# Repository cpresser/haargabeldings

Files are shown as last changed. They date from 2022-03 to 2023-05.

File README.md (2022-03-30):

# HaarGabelDings

action shot
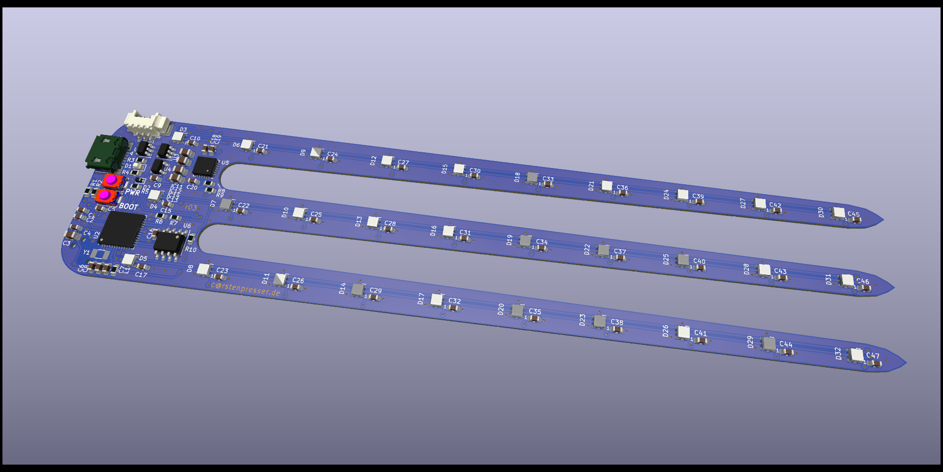
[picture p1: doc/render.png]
render


# Hardware
The current revision uses a SAMD21 MCU, making it compatible with the `Arduino Zero` and the `Adafruit Feather M0 Express`.

Since there was no space left to route tracks or put parts, no other Pins are broken out. Also there is no USB ESD Protection.

## PCB
Export gerbers and order it at you favorite fab.
The first proto used 2mm FR4 instead of the default 1.5mm and is quite usable. Perhaps 3mm is even better.. who knows? One might even try to glue two PCBs together somehow to make the whole thing stiffer.

## Coating?
Some coating is required, otherwise the assembled PCB has to many sharp edges which makes it unusable as a hairpiece. I used epoxy for the prototype. Make sure to mask the switch, debugger-port and USB-connector. You don't want them covered in epoxy (I have been there, don't repeat my mistakes).

## BOM
Nope. I might add one later.

All parts are available at digikey though - assuming there is no global semiconductor supplychain crisis.

## Battery
Connect any single cell lipo battery. I recommend to get one with a build in battery management system.

# Software
The v3 version is supposed to be compatible with the "Adafruit Feather M0 Express", which means one can use micropython.

## USB Bootloader
The Adafruit or Arduino Bootloader should work.

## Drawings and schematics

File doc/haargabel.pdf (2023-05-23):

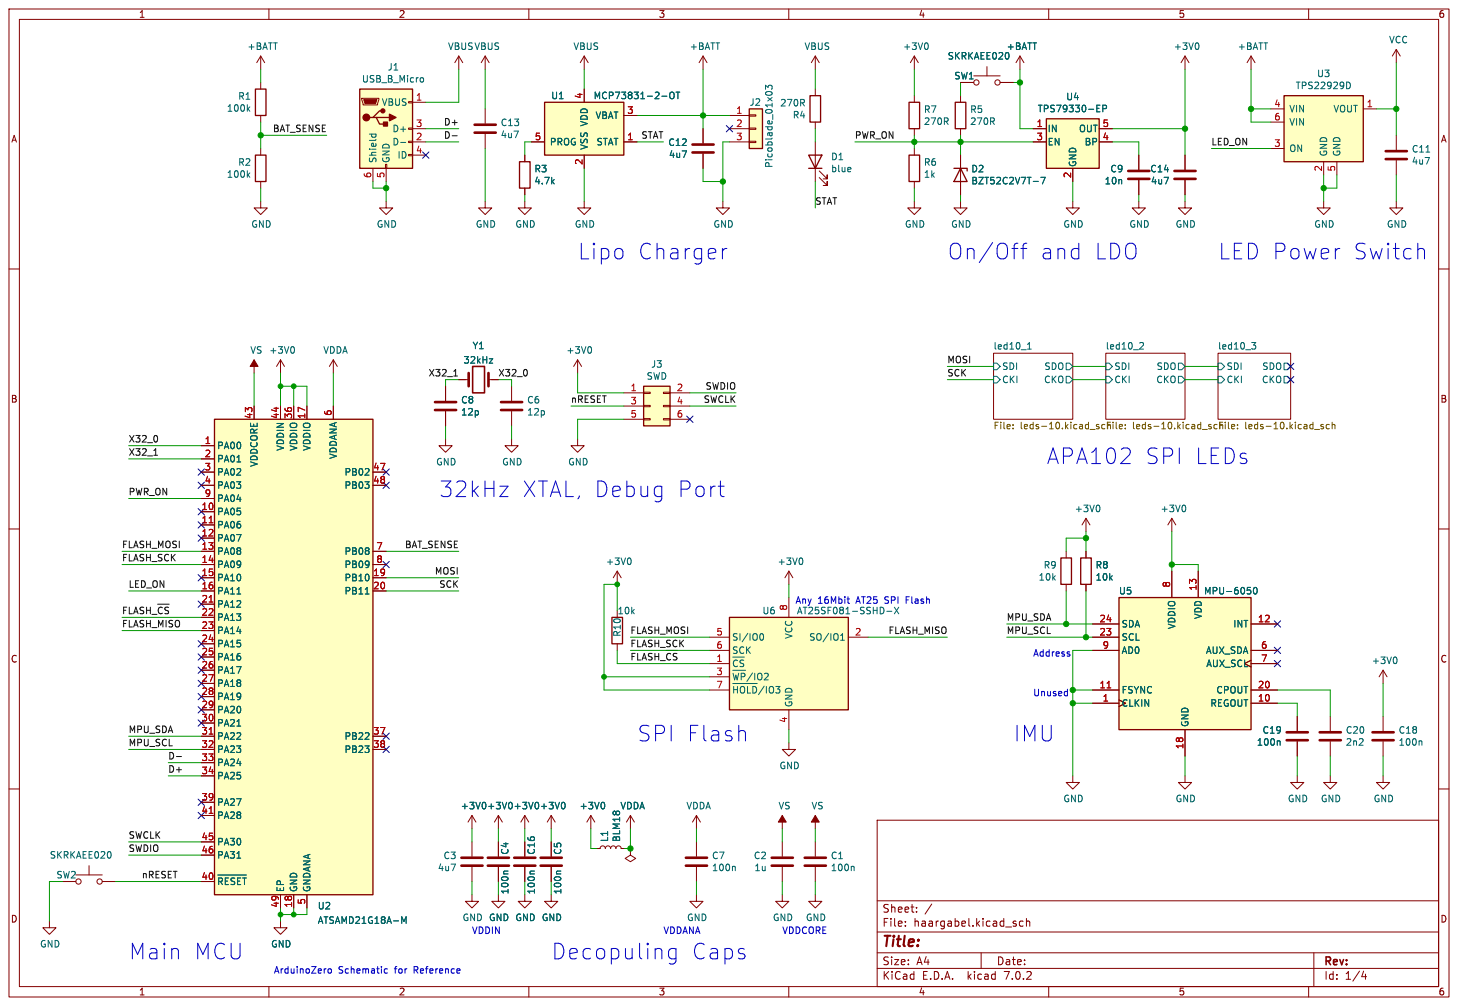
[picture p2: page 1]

2 EN 3 BP 4 OUT 5 SW1 SKRKAEE020+BATT D2BZT52C2V7T-7 C12

2 EN 3 BP 4 OUT 5 U4 TPS79330-EP GND

4u7 GND GND GND GND

Unused Address Lipo Charger

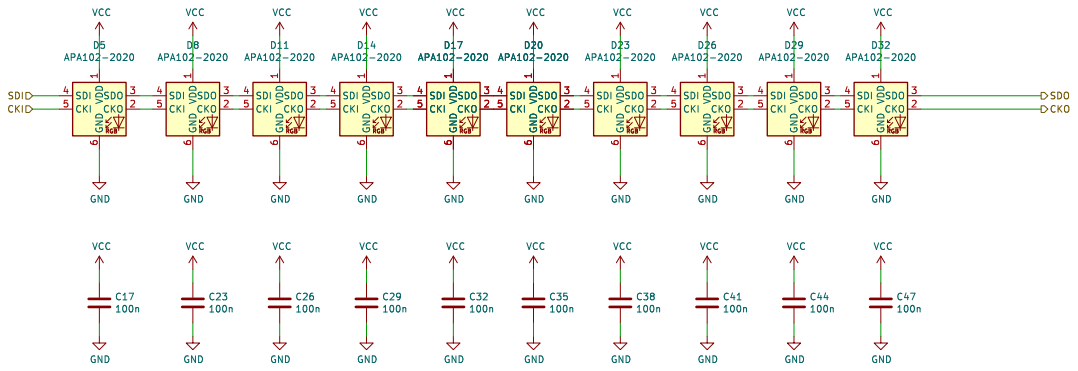
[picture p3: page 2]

6 D32 APA102-2020 GND GND GND GND GND

1 CKO 2 SDO 3 SDI 4 CKI 5 GND
RGB VDD

Id: 2/4 Title: File: leds-10.kicad_sch Sheet: /led10_1/ GND

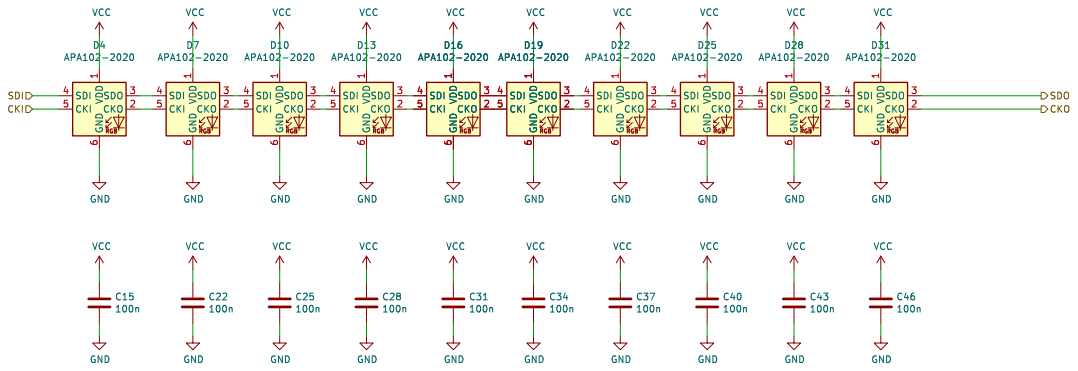
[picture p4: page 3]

6 D28 APA102-2020 GND GND GND GND GND

1 CKO 2 SDO 3 SDI 4 CKI 5 GND
RGB VDD

Id: 3/4 Title: File: leds-10.kicad_sch Sheet: /led10_2/

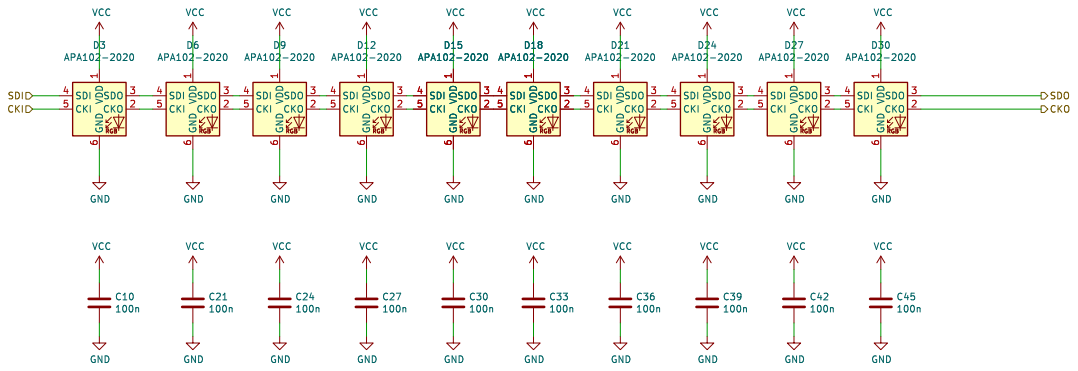
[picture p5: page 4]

6 D27 APA102-2020 VCC GND GND GND GND GND

1 CKO 2 SDO 3 SDI 4 CKI 5 GND
RGB VDD

Id: 4/4 Title: File: leds-10.kicad_sch Sheet: /led10_3/ GND

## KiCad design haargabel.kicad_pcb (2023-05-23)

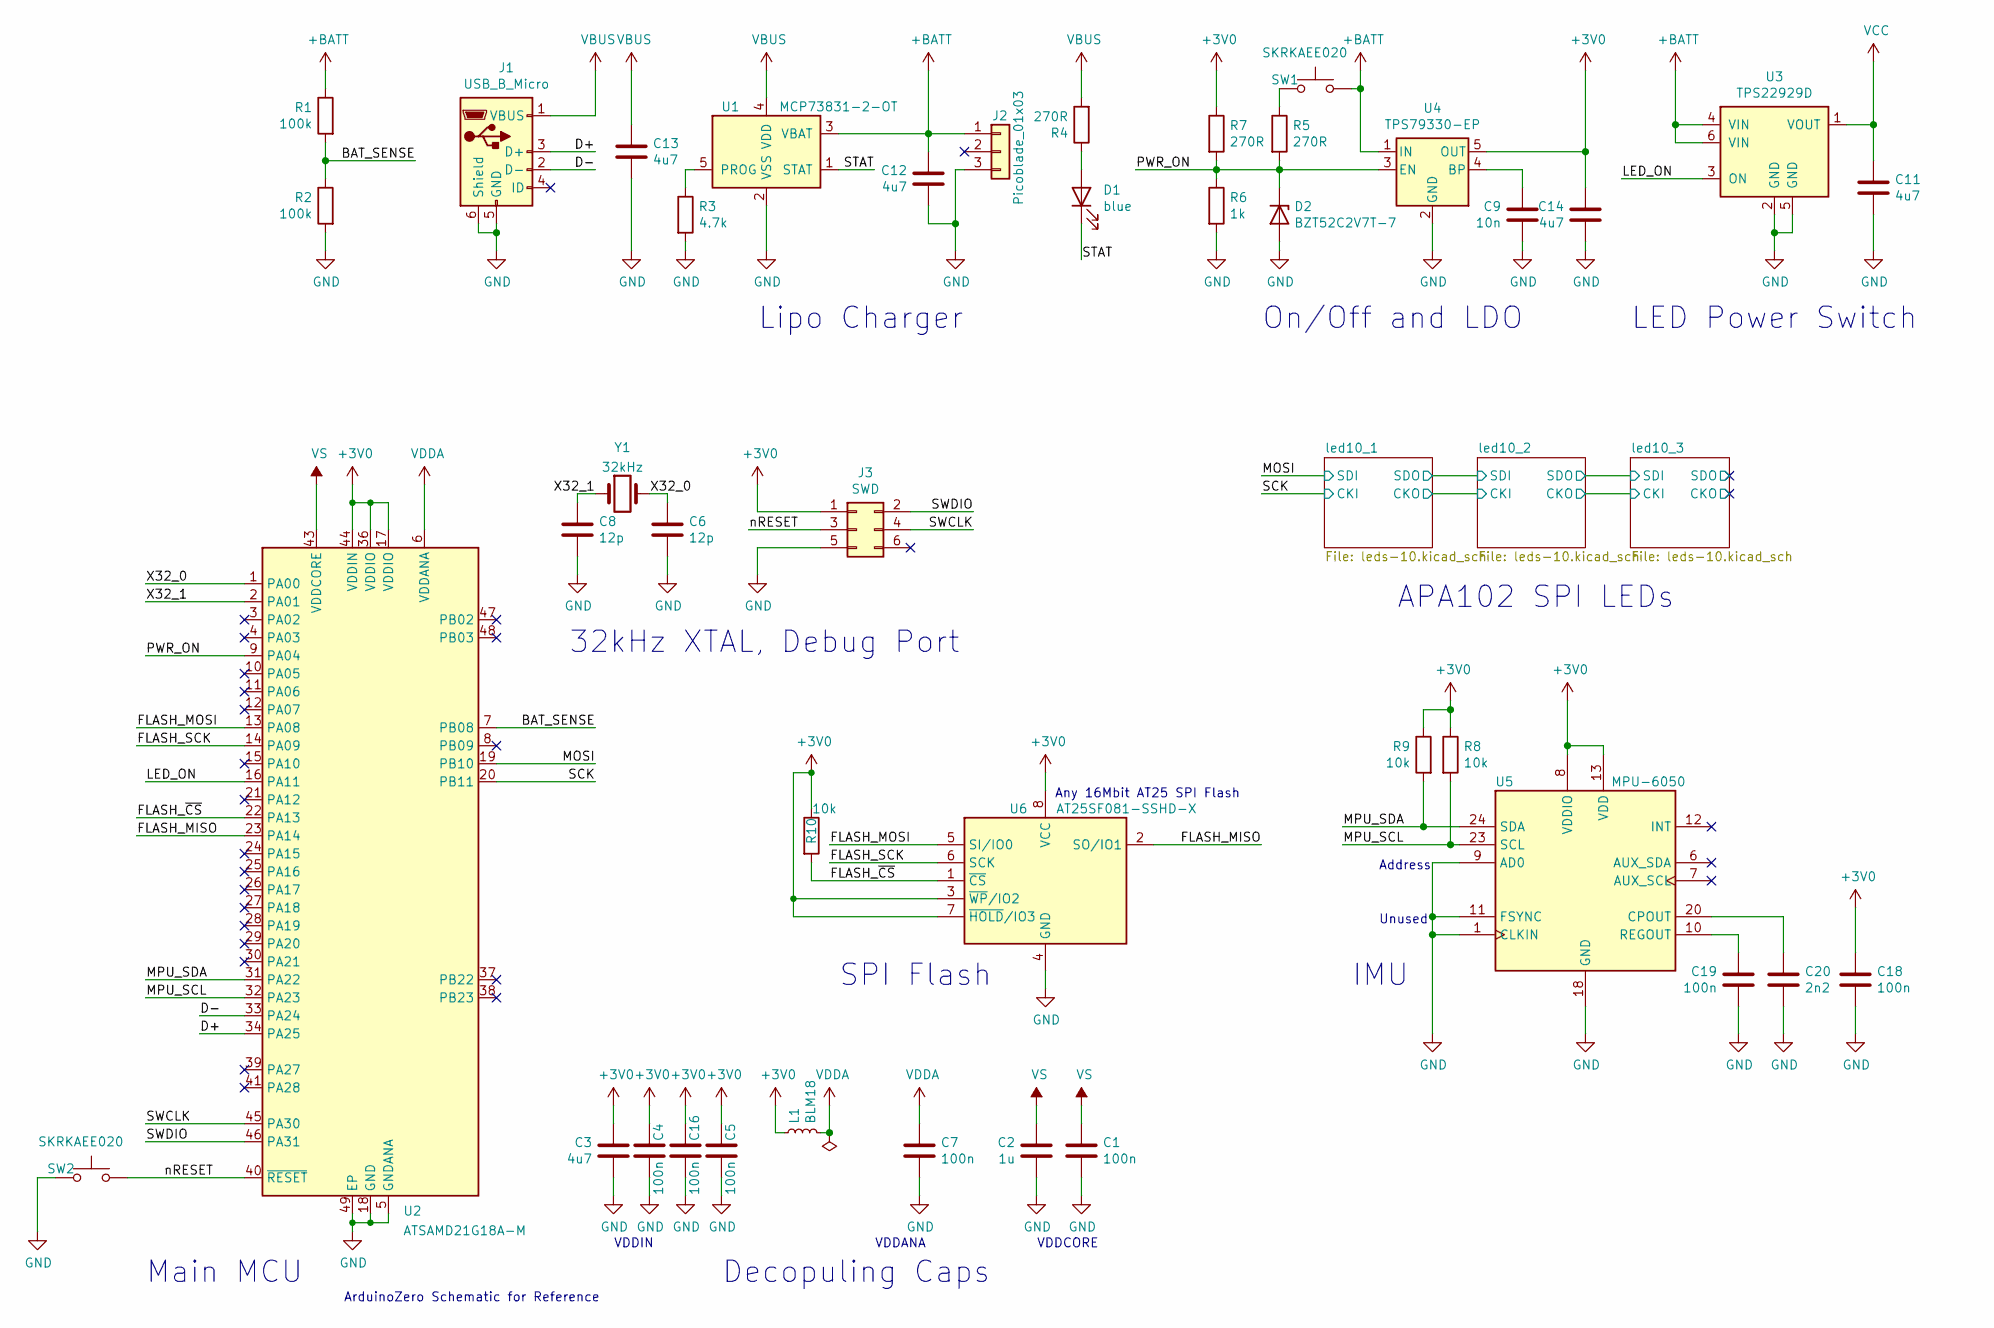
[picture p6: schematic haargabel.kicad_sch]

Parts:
C1, C4, C5, C7, C16, C18, C19: 100n; C_0603_1608Metric
C2: 1u; C_0603_1608Metric
C3, C11, C12, C13, C14: 4u7; C_0805_2012Metric
C6, C8: 12p; C_0603_1608Metric
C9: 10n; C_0603_1608Metric
C20: 2n2; C_0603_1608Metric
D1: blue; LED_0603_1608Metric
D2: BZT52C2V7T-7; D_SOD-523
J1: USB_B_Micro; USB_Micro-B_Amphenol_10103594-0001LF_Horizontal
J2: Picoblade_01x03; Molex_PicoBlade_53261-0371_1x03-1MP_P1.25mm_Horizontal
J3: SWD; Tag-Connect_TC2030-IDC-NL_2x03_P1.27mm_Vertical
L1: BLM18; R_0603_1608Metric
R1, R2: 100k; R_0603_1608Metric
R3: 4.7k; R_0603_1608Metric
R4, R5, R7: 270R; R_0603_1608Metric
R6: 1k; R_0603_1608Metric
R8, R9, R10: 10k; R_0603_1608Metric
SW1, SW2: SKRKAEE020; SW_Push_SPST_NO_Alps_SKRK
U1: MCP73831-2-OT; SOT-23-5
U2: ATSAMD21G18A-M; QFN-48-1EP_7x7mm_P0.5mm_EP5.15x5.15mm
U3: TPS22929D; SOT-23-6
U4: TPS79330-EP; SOT-23-5
U5: MPU-6050; InvenSense_QFN-24_4x4mm_P0.5mm
U6: AT25SF081-SSHD-X; SOIC-8_3.9x4.9mm_P1.27mm
Y1: 32kHz; Crystal_SMD_3215-2Pin_3.2x1.5mm

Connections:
+3V0: C3.2, C4.1, C5.1, C14.2, C16.1, C18.1, J3.1, L1.1, R7.1, R8.1, R9.1, R10.1, U2.17 (VDDIO), U2.36 (VDDIO), U2.44 (VDDIN), U4.5 (OUT), U5.8 (VDDIO), U5.13 (VDD), U6.3 (~WP/IO2), U6.7 (~HOLD/IO3), U6.8 (VCC)
+BATT: C12.2, J2.1, R1.1, SW1.1, U1.3 (VBAT), U3.4 (VIN), U3.6 (VIN), U4.1 (IN)
/BAT_SENSE: R1.2, R2.1, U2.7 (PB08)
/D+: J1.3 (D+), U2.34 (PA25)
/D-: J1.2 (D-), U2.33 (PA24)
/FLASH_MISO: U2.23 (PA14), U6.2 (SO/IO1)
/FLASH_MOSI: U2.13 (PA08), U6.5 (SI/IO0)
/FLASH_SCK: U2.14 (PA09), U6.6 (SCK)
/FLASH_~CS: R10.2, U2.22 (PA13), U6.1 (~CS)
/LED_ON: U2.16 (PA11), U3.3 (ON)
/MOSI: U2.19 (PB10); also elsewhere on the board
/MPU_SCL: R8.2, U2.32 (PA23), U5.23 (SCL)
/MPU_SDA: R9.2, U2.31 (PA22), U5.24 (SDA)
/PWR_ON: D2.1 (K), R5.2, R6.1, R7.2, U2.9 (PA04), U4.3 (EN)
/SCK: U2.20 (PB11); also elsewhere on the board
/STAT: D1.1 (K), U1.1 (STAT)
/SWCLK: J3.4, U2.45 (PA30)
/SWDIO: J3.2, U2.46 (PA31)
/X32_0: C6.1, U2.1 (PA00), Y1.2
/X32_1: C8.1, U2.2 (PA01), Y1.1
/nRESET: J3.3, SW2.1, U2.40 (~RESET)
GND: C1.2, C2.2, C3.1, C4.2, C5.2, C6.2, C7.2, C8.2, C9.1, C11.1, C12.1, C13.2, C14.1, C16.2, C18.2, C19.2, C20.2, D2.2 (A), J1.5 (GND), J1.6 (Shield), J2.3, J3.5, R2.2, R3.2, R6.2, SW2.2, U1.2 (VSS), U2.5 (GNDANA), U2.18 (GND), U2.35 (GND), U2.42 (GND), U2.49 (EP), U3.2 (GND), U3.5 (GND), U4.2 (GND), U5.1 (CLKIN), U5.9 (AD0), U5.11 (FSYNC), U5.18 (GND), U6.4 (GND); also elsewhere on the board
unnamed: D1.2 (A), R4.1
unnamed: R5.1, SW1.2
unnamed: R3.1, U1.5 (PROG)
unnamed: C9.2, U4.4 (BP)
unnamed: C20.1, U5.20 (CPOUT)
unnamed: C19.1, U5.10 (REGOUT)
VBUS: C13.1, J1.1 (VBUS), R4.2, U1.4 (VDD)
VCC: C11.2, U3.1 (VOUT); also elsewhere on the board
VDDA: C7.1, L1.2, U2.6 (VDDANA)
VS: C1.1, C2.1, U2.43 (VDDCORE)

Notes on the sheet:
32kHz XTAL, Debug Port
Unused
On/Off and LDO
VDDCORE
SPI Flash
ArduinoZero Schematic for Reference
Lipo Charger
Decopuling Caps
VDDIN
LED Power Switch
Address
Main MCU
APA102 SPI LEDs
VDDANA
IMU
Any 16Mbit AT25 SPI Flash

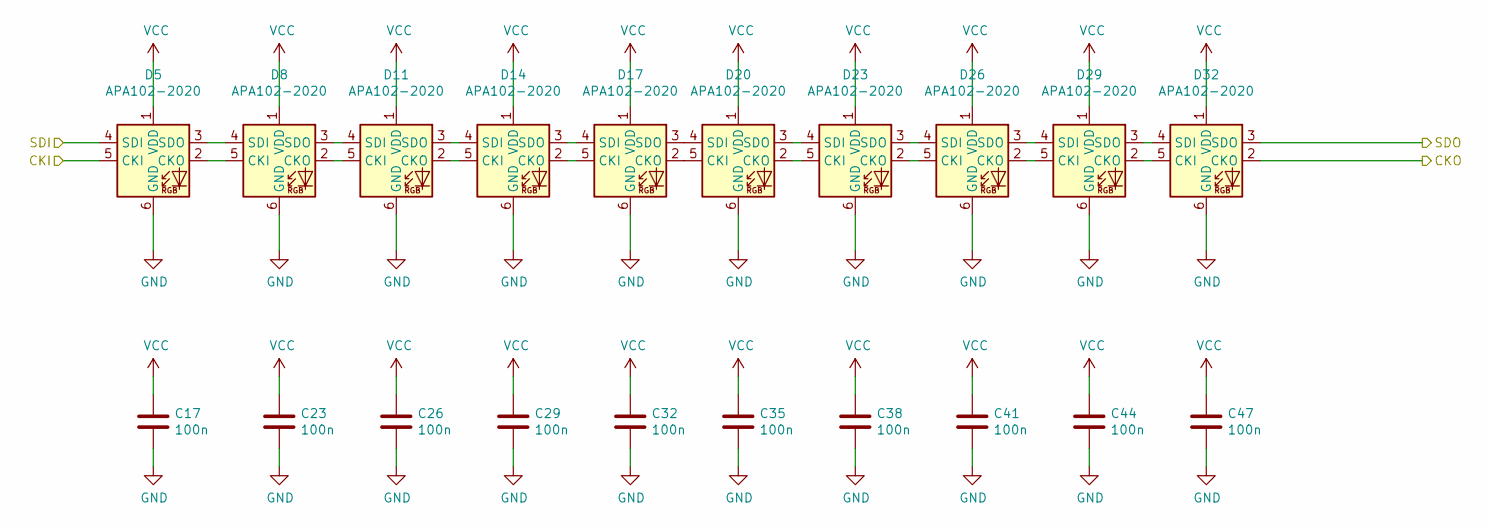
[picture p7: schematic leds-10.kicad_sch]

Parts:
C17, C23, C26, C29, C32, C35, C38, C41, C44, C47: 100n; C_0603_1608Metric
D5, D8, D11, D14, D17, D20, D23, D26, D29, D32: APA102-2020; LED-APA102-2020

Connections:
/MOSI: D5.4 (SDI); also elsewhere on the board
/SCK: D5.5 (CKI); also elsewhere on the board
/led10_1/CKO: D32.2 (CKO); also elsewhere on the board
/led10_1/SDO: D32.3 (SDO); also elsewhere on the board
GND: C17.2, C23.2, C26.2, C29.2, C32.2, C35.2, C38.2, C41.2, C44.2, C47.2, D5.6 (GND), D8.6 (GND), D11.6 (GND), D14.6 (GND), D17.6 (GND), D20.6 (GND), D23.6 (GND), D26.6 (GND), D29.6 (GND), D32.6 (GND); also elsewhere on the board
unnamed: D5.2 (CKO), D8.5 (CKI)
unnamed: D5.3 (SDO), D8.4 (SDI)
unnamed: D8.2 (CKO), D11.5 (CKI)
unnamed: D11.2 (CKO), D14.5 (CKI)
unnamed: D8.3 (SDO), D11.4 (SDI)
unnamed: D11.3 (SDO), D14.4 (SDI)
unnamed: D14.2 (CKO), D17.5 (CKI)
unnamed: D14.3 (SDO), D17.4 (SDI)
unnamed: D17.2 (CKO), D20.5 (CKI)
unnamed: D17.3 (SDO), D20.4 (SDI)
unnamed: D20.2 (CKO), D23.5 (CKI)
unnamed: D20.3 (SDO), D23.4 (SDI)
unnamed: D23.2 (CKO), D26.5 (CKI)
unnamed: D23.3 (SDO), D26.4 (SDI)
unnamed: D26.2 (CKO), D29.5 (CKI)
unnamed: D26.3 (SDO), D29.4 (SDI)
unnamed: D29.2 (CKO), D32.5 (CKI)
unnamed: D29.3 (SDO), D32.4 (SDI)
VCC: C17.1, C23.1, C26.1, C29.1, C32.1, C35.1, C38.1, C41.1, C44.1, C47.1, D5.1 (VDD), D8.1 (VDD), D11.1 (VDD), D14.1 (VDD), D17.1 (VDD), D20.1 (VDD), D23.1 (VDD), D26.1 (VDD), D29.1 (VDD), D32.1 (VDD); also elsewhere on the board

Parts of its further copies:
C10, C15, C21, C22, C24, C25, C27, C28, C30, C31, C33, C34, C36, C37, C39, C40, C42, C43, C45, C46: 100n; C_0603_1608Metric
D3, D4, D6, D7, D9, D10, D12, D13, D15, D16, D18, D19, D21, D22, D24, D25, D27, D28, D30, D31: APA102-2020; LED-APA102-2020

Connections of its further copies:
/led10_1/CKO: D4.5 (CKI); also elsewhere on the board
/led10_1/SDO: D4.4 (SDI); also elsewhere on the board
/led10_2/CKO: D3.5 (CKI), D31.2 (CKO)
/led10_2/SDO: D3.4 (SDI), D31.3 (SDO)
/led10_3/CKO: D30.2 (CKO)
/led10_3/SDO: D30.3 (SDO)
GND: C10.2, C15.2, C21.2, C22.2, C24.2, C25.2, C27.2, C28.2, C30.2, C31.2, C33.2, C34.2, C36.2, C37.2, C39.2, C40.2, C42.2, C43.2, C45.2, C46.2, D3.6 (GND), D4.6 (GND), D6.6 (GND), D7.6 (GND), D9.6 (GND), D10.6 (GND), D12.6 (GND), D13.6 (GND), D15.6 (GND), D16.6 (GND), D18.6 (GND), D19.6 (GND), D21.6 (GND), D22.6 (GND), D24.6 (GND), D25.6 (GND), D27.6 (GND), D28.6 (GND), D30.6 (GND), D31.6 (GND); also elsewhere on the board
unnamed: D3.2 (CKO), D6.5 (CKI)
unnamed: D3.3 (SDO), D6.4 (SDI)
unnamed: D4.2 (CKO), D7.5 (CKI)
unnamed: D4.3 (SDO), D7.4 (SDI)
unnamed: D6.2 (CKO), D9.5 (CKI)
unnamed: D6.3 (SDO), D9.4 (SDI)
unnamed: D7.2 (CKO), D10.5 (CKI)
unnamed: D10.2 (CKO), D13.5 (CKI)
unnamed: D7.3 (SDO), D10.4 (SDI)
unnamed: D10.3 (SDO), D13.4 (SDI)
unnamed: D9.2 (CKO), D12.5 (CKI)
unnamed: D12.2 (CKO), D15.5 (CKI)
unnamed: D9.3 (SDO), D12.4 (SDI)
unnamed: D12.3 (SDO), D15.4 (SDI)
unnamed: D13.2 (CKO), D16.5 (CKI)
unnamed: D13.3 (SDO), D16.4 (SDI)
unnamed: D15.2 (CKO), D18.5 (CKI)
unnamed: D15.3 (SDO), D18.4 (SDI)
unnamed: D16.2 (CKO), D19.5 (CKI)
unnamed: D16.3 (SDO), D19.4 (SDI)
unnamed: D18.2 (CKO), D21.5 (CKI)
unnamed: D18.3 (SDO), D21.4 (SDI)
unnamed: D19.2 (CKO), D22.5 (CKI)
unnamed: D19.3 (SDO), D22.4 (SDI)
unnamed: D21.2 (CKO), D24.5 (CKI)
unnamed: D21.3 (SDO), D24.4 (SDI)
unnamed: D22.2 (CKO), D25.5 (CKI)
unnamed: D22.3 (SDO), D25.4 (SDI)
unnamed: D24.2 (CKO), D27.5 (CKI)
unnamed: D24.3 (SDO), D27.4 (SDI)
unnamed: D25.2 (CKO), D28.5 (CKI)
unnamed: D25.3 (SDO), D28.4 (SDI)
unnamed: D27.2 (CKO), D30.5 (CKI)
unnamed: D27.3 (SDO), D30.4 (SDI)
unnamed: D28.2 (CKO), D31.5 (CKI)
unnamed: D28.3 (SDO), D31.4 (SDI)
VCC: C10.1, C15.1, C21.1, C22.1, C24.1, C25.1, C27.1, C28.1, C30.1, C31.1, C33.1, C34.1, C36.1, C37.1, C39.1, C40.1, C42.1, C43.1, C45.1, C46.1, D3.1 (VDD), D4.1 (VDD), D6.1 (VDD), D7.1 (VDD), D9.1 (VDD), D10.1 (VDD), D12.1 (VDD), D13.1 (VDD), D15.1 (VDD), D16.1 (VDD), D18.1 (VDD), D19.1 (VDD), D21.1 (VDD), D22.1 (VDD), D24.1 (VDD), D25.1 (VDD), D27.1 (VDD), D28.1 (VDD), D30.1 (VDD), D31.1 (VDD); also elsewhere on the board

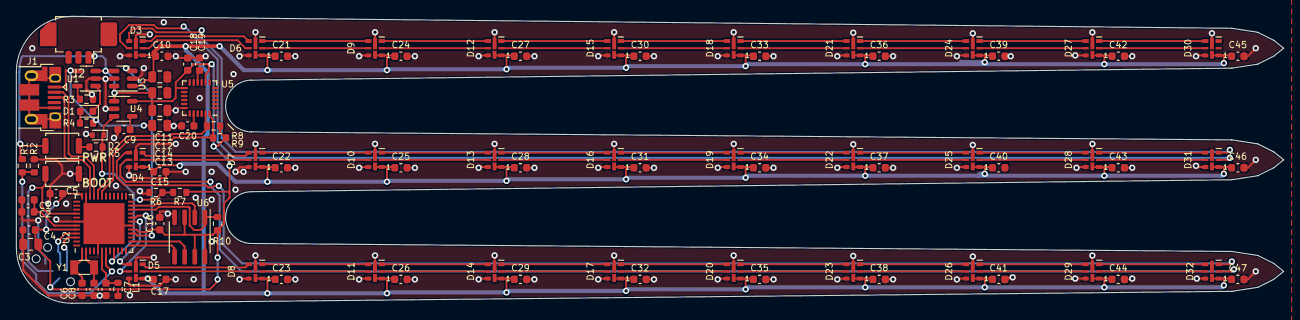
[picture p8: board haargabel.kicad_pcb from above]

Board: 2 copper layers, 159.0 x 36.0 mm, 102 parts (1 on the bottom side), 90 nets.

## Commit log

2019-04-10 Better B.SilkS text
    [haargabel.kicad_pcb]
2019-05-30 Fix startup circuit
    Use a zener-diode instead of just resistors.
    This makes stuff much easier since it 'protects' the CPU from the high battery voltage.
    [haargabel.kicad_pcb, haargabel.sch, leds-8.sch]
2019-05-30 Remove the DIY-Panel, make it more pointy
    The Fab will fuck up the routing anyway. Lets just hope they place the tabs somewhat reasonable.
    The round ends were not pointy enough, fix them.
    [haargabel.kicad_pcb]
2019-05-30 Make it longer
    Add two more LEDs, making the whole thing 30mm longer
    [haargabel.kicad_pcb, haargabel.sch, leds-10.sch]
2019-05-30 Re-Annotate, so the LED numbering makes more sense
    [haargabel.kicad_pcb, haargabel.sch, leds-10.sch]
2019-05-31 Move bottom silkscreen
    [haargabel.kicad_pcb]
2020-10-17 Add schematic as doc/haargabel.pdf
2022-03-27 Use a different MCU to make programming easier
    [haargabel.kicad_pcb, haargabel.kicad_sch, haargabel.sch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]
2022-03-27 Add Silkscreen for the buttons
    [haargabel.kicad_pcb]
2023-05-23 Convert to KiCad7, add iBOM
    [haargabel.kicad_pcb, haargabel.kicad_sch, leds-10.kicad_sch]
2023-05-23 Simplify component values
    [haargabel.kicad_pcb, haargabel.kicad_sch]
